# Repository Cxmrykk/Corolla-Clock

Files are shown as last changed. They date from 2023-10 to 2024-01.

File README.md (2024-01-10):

<h1 align=center>Toyota Corolla AMOLED Clock</h1>
<p align=center>Custom clock project using the LilyGo T-Display-S3 AMOLED</p>

<div align=center>
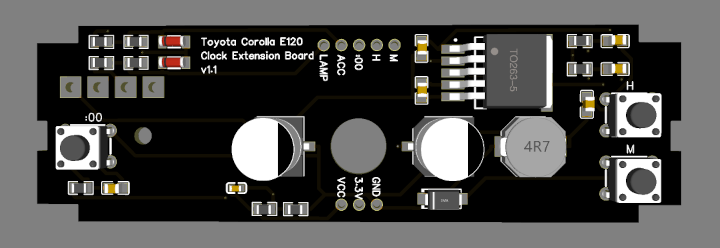
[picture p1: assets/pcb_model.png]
    
</div>

### Features
- Display the time on a high resolution AMOLED display
- Different colour/brightness based on interior lighting state (on/off)
- Colour Settings (digit colour, background opacity, whiteness level)
- Size Settings (width, thickness, padding)
- Automatic display timeout when accessory is off

### Dependencies
- **ESP-IDF** <= v4.4.6
- **Arduino-ESP32** <= v2.0.14 *(Place inside components folder)*
- **TFT-eSPI** <= v2.5.31 *(Place inside components folder)*
- **Required Libraries** (See [Official ESP-IDF Installation Steps](https://docs.espressif.com/projects/esp-idf/en/latest/esp32/get-started/linux-macos-setup.html))
    - Additionally: `python3-virtualenv`

### Configuration
- **menuconfig** *(Type "menuconfig" in Command Palette)*
    - Set all `TFT_eSPI` driver configuration pins to 0 (we are using `rm67162.h` and `rm67162.cpp` for driving the display)
    - `"Autostart Arduino setup and loop on boot"` should be enabled
- **CMakeLists.txt**
    - Make sure `main.cpp` and `rm67162.cpp` are both in `SRCS` entry for `idf_component_register`
    - `INCLUDE_DIRS` should be set to `"."` (Relative path of `main` directory, includes the header files)
- **VSCode (ESP-IDF)**
    - Set device to `esp32s3`
    - Set flash method to `UART`

### Step-by-Step DIY Tutorial
> This project requires a clock with 3 buttons (Asia/Pacific Model). If your clock does not meet this specification, you will need to purchase a separate clock housing.<br>
> A Linux-based OS is necessary to flash the software. **Debian Desktop or Ubuntu** are recommended.

1. **Procure T-Display-S3 AMOLED and Necessary Materials**
    - **T-Display-S3 Amoled** (https://www.lilygo.cc/products/t-display-s3-amoled)
    - Wire cutters
    - Soldering iron
    - Solder
    - Heat-resistant cables (compatible with 2.54mm spaced pins)

2. **Order PCB via JLCPCB Service**
    - Register an account at https://jlcpcb.com/
    - Navigate to https://cart.jlcpcb.com/quote/Upload and upload the gerber file located in `/docs/schematics`
    - Select "PCB Assembly"
    - Proceed with the checkout process, providing the files located in `docs/schematics`.

3. **Order 3D Print via JLC3DP Service**
    - Log in using the same account
    - Repeat the following process for both models:
        - Navigate to https://jlc3dp.com/3d-printing-quote and upload the STL file located in `/docs/models`
        - Choose a material that can withstand high temperatures
        - Add to cart and proceed with the checkout process

4. **Software Flashing**
    - Download Visual Studio Code from https://code.visualstudio.com
    - Install the dependencies as specified in the README
    - Follow the configuration steps as specified in the README
        - Clone the project: `git clone https://github.com/Cxmrykk/Corolla-Clock.git`
        - Navigate to the project directory: `cd Corolla-Clock`
        - Open with VSCode: `code .`
    - Connect the T-Display-S3 AMOLED board via USB-C and click the "Flash" button at the bottom

5. **Soldering Process**
    - Trim the wires on both sides (approximately 0.5cm) and tin them using the soldering iron
    - Solder wires to the T-Display-S3 AMOLED pins as follows:
        - GPIO 42: LAMP
        - GPIO 43: ACCESSORY
        - GPIO 44: RESET
        - GPIO 45: HOUR
        - GPIO 46: MINUTE
        - VBUS: VCC
        - 3.3V: 3.3V
        - GND: GND
    - After soldering, trim the ends to prevent contact (trim the top of the board, not the cables)
    - Solder the other ends of the cables to the PCB (refer to the pin map above)
    - Verify that all pins are soldered and none are touching

6. **Clock Removal and Assembly**
    - Remove the clock by following a tutorial on YouTube
    - Disassemble the clock by following a tutorial on YouTube (Exercise caution as the clock housing clips are brittle)
    - Remove the existing buttons and circuit board
    - Secure the new PCB to the clock housing using the existing screw
    - Insert the 3D printed mount and buttons (some force may be required for proper insertion)
    - Insert the Screen and PCB:
        - The USB-C port should be on the right side. The LILYGO logo should be upright (same orientation as clock housing)
        - Insert the screen first, then clip in the rest of the housing (with the PCB attached)
    - Finally, reinstall the clock and reassemble your car.

7. **Adjusting Alignment and Time**
    - Press the reset button (`:00`) to toggle the mode overlay
    - Press the hour button twice (`H`) to cycle to the vertical positioning menu
    - Press the reset button once more and hold the `H` and `M` buttons to adjust the screen position
    - Adjust the screen position as needed for clear text readability
    - Configure your clock as required (Set time, align screen, colours, sizing, brightness, etc)

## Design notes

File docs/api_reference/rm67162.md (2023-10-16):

# RM67162 C++ File Documentation

## Overview

This C++ file, `rm67162.cpp`, provides functions and commands for controlling the RM67162 display using the Arduino platform. The RM67162 is a display controller used in various TFT displays.

## Included Libraries

The file includes several libraries to support display communication and control:

- `rm67162.h`: A custom header file containing necessary declarations and constants for the RM67162 display.
- `SPI.h`: The Arduino SPI library for SPI communication.
- `Arduino.h`: The Arduino core library for general Arduino functions.
- `driver/spi_master.h`: ESP-IDF library for SPI communication on ESP32-based devices.

## Global Variables

### `rm67162_spi_init`

An array of `lcd_cmd_t` structures containing initialization commands for the RM67162 display when using SPI communication.

### `rm67162_qspi_init`

An array of `lcd_cmd_t` structures containing initialization commands for the RM67162 display when using Quad SPI (QSPI) communication.

### `spi`

A static variable of type `spi_device_handle_t` to manage SPI communication.

## Functions

### `WriteComm(uint8_t data)`

- Writes a command byte to the RM67162 display.
- Parameters:
  - `data`: The command byte to be written.

### `WriteData(uint8_t data)`

- Writes data to the RM67162 display.
- Parameters:
  - `data`: The data byte to be written.

### `WriteData16(uint16_t data)`

- Writes a 16-bit data word to the RM67162 display.
- Parameters:
  - `data`: The 16-bit data word to be written.

### `lcd_send_cmd(uint32_t cmd, uint8_t *dat, uint32_t len)`

- Sends a command and optional data to the display.
- Parameters:
  - `cmd`: The command code to be sent.
  - `dat`: An array of data bytes to be sent (can be `NULL`).
  - `len`: The length of the data to be sent.

### `rm67162_init()`

- Initializes the RM67162 display, configures the SPI communication, and sends initialization commands.

### `lcd_setRotation(uint8_t r)`

- Sets the display rotation.
- Parameters:
  - `r`: The rotation value (0, 1, 2, or 3).

### `lcd_address_set(uint16_t x1, uint16_t y1, uint16_t x2, uint16_t y2)`

- Sets the display address window for drawing operations.
- Parameters:
  - `x1`, `y1`: Coordinates of the top-left corner.
  - `x2`, `y2`: Coordinates of the bottom-right corner.

### `lcd_fill(uint16_t xsta, uint16_t ysta, uint16_t xend, uint16_t yend, uint16_t color)`

- Fills a rectangular area with a specified color.
- Parameters:
  - `xsta`, `ysta`: Coordinates of the top-left corner.
  - `xend`, `yend`: Coordinates of the bottom-right corner.
  - `color`: The fill color.

### `lcd_DrawPoint(uint16_t x, uint16_t y, uint16_t color)`

- Draws a single pixel at the specified coordinates with the given color.
- Parameters:
  - `x`, `y`: Coordinates of the pixel.
  - `color`: The pixel color.

### `lcd_PushColors(uint16_t x, uint16_t y, uint16_t width, uint16_t high, uint16_t *data)`

- Pushes an array of color data to the display at the specified coordinates.
- Parameters:
  - `x`, `y`: Coordinates of the top-left corner.
  - `width`, `high`: Width and height of the data area.
  - `data`: An array of color data.

### `lcd_PushColors(uint16_t *data, uint32_t len)`

- Pushes an array of color data to the display without specifying coordinates.
- Parameters:
  - `data`: An array of color data.
  - `len`: The length of the data.

### `lcd_sleep()`

- Puts the display to sleep mode.

### `lcd_brightness(uint8_t bright)`

- Sets the display brightness.
- Parameters:
  - `bright`: The brightness value.

### `lcd_set_colour_enhance(uint8_t enh)`

- Sets color enhancement for the display.
- Parameters:
  - `enh`: Color enhancement value.

### `lcd_display_off()`

- Turns off the display.

### `lcd_display_on()`

- Turns on the display.

### `lcd_display_invert_on()`

- Enables display inversion.

### `lcd_display_invert_off()`

- Disables display inversion.

### `lcd_display_set_colour_enhance_low_byte(uint8_t ce_low_byte)`

- Sets the low byte of color enhancement.

### `lcd_display_set_colour_enhance_high_byte(uint8_t ce_high_byte)`

- Sets the high byte of color enhancement.

### `lcd_display_high_brightness_mode_on(uint8_t hbm_en)`

- Enables high brightness mode.

### `lcd_display_high_brightness_mode_off(uint8_t hbm_en)`

- Disables high brightness mode.

## Note

- The code includes conditional compilation directives (`#if`) to support different display drivers and communication methods. Please ensure that the correct configuration is used for your specific setup.
- Some functions may not be implemented or used in your specific application. Modify the code as needed for your project.

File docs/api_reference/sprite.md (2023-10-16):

# TFT_eSprite Class Documentation

The `TFT_eSprite` class is a C++ class designed to create and manipulate sprites in RAM that can be used for efficient graphics rendering on TFT screens. It is a subclass of the `TFT_eSPI` class and inherits graphics functions from it. This class is particularly useful for creating and rendering graphics on TFT displays. 

## Constructor

### `explicit TFT_eSprite(TFT_eSPI *tft)`
- Constructor for the `TFT_eSprite` class. It takes a pointer to an instance of the `TFT_eSPI` class as a parameter and initializes a sprite.

## Destructor

### `~TFT_eSprite(void)`
- Destructor for the `TFT_eSprite` class. Deallocates memory used by the sprite.

## Sprite Creation

### `void* createSprite(int16_t width, int16_t height, uint8_t frames = 1)`
- Creates a sprite with the specified width, height, and number of frames. Returns a pointer to the RAM area used by the sprite.

### `void* getPointer(void)`
- Returns a pointer to the sprite's memory. Returns `nullptr` if the sprite has not been created.

### `bool created(void)`
- Checks if a sprite has been created and returns `true` if it has.

### `void deleteSprite(void)`
- Deletes the sprite and frees up the RAM used by it.

## Frame Buffer Selection

### `void* frameBuffer(int8_t f)`
- Selects the frame buffer for graphics write. Returns a pointer to the sprite's frame buffer.

## Color Depth

### `void* setColorDepth(int8_t b)`
- Sets the color depth of the sprite to 1, 4, 8, or 16 bits. Returns a new pointer to the sprite if it's re-created with the new depth.

### `int8_t getColorDepth(void)`
- Returns the current color depth of the sprite.

## Palette

### `void createPalette(uint16_t *palette = nullptr, uint8_t colors = 16)`
- Sets the palette for a 4-bit depth sprite. The palette is an array of 16 colors, and only the first 16 colors in the map are used.

### `void createPalette(const uint16_t *palette = nullptr, uint8_t colors = 16)`
- Sets the palette for a 4-bit depth sprite from flash memory.

### `void setPaletteColor(uint8_t index, uint16_t color)`
- Sets the color for a specific index in the palette.

### `uint16_t getPaletteColor(uint8_t index)`
- Retrieves the color at the specified palette index.

## Graphics Drawing

### `void drawPixel(int32_t x, int32_t y, uint32_t color)`
- Draws a single pixel at the specified x and y coordinates with the given color.

### `void drawChar(int32_t x, int32_t y, uint16_t c, uint32_t color, uint32_t bg, uint8_t size)`
- Draws a single character in the GLCD or GFXFF font.

### `void fillSprite(uint32_t color)`
- Fills the entire sprite with the specified color.

### `void setWindow(int32_t x0, int32_t y0, int32_t x1, int32_t y1)`
- Defines a window in the sprite for drawing, which is used for subsequent graphics operations within the defined area.

### `void pushColor(uint16_t color)`
- Pushes a single color (pixel) to the sprite's set window area.

### `void pushColor(uint16_t color, uint32_t len)`
- Pushes multiple colors (pixels) to the sprite's set window area.

### `void writeColor(uint16_t color)`
- Pushes a pre-formatted pixel with 1, 4, 8, or 16-bit color depth to the sprite's set window area.

### `void drawLine(int32_t x0, int32_t y0, int32_t x1, int32_t y1, uint32_t color)`
- Draws a line between two points with the specified color.

### `void drawFastVLine(int32_t x, int32_t y, int32_t h, uint32_t color)`
- Draws a vertical line with the specified color.

### `void drawFastHLine(int32_t x, int32_t y, int32_t w, uint32_t color)`
- Draws a horizontal line with the specified color.

### `void fillRect(int32_t x, int32_t y, int32_t w, int32_t h, uint32_t color)`
- Fills a rectangular area with the specified color, effectively drawing a filled rectangle.

## Sprite Rotation

### `void setRotation(uint8_t rotation)`
- Sets the coordinate rotation of the sprite. This is primarily for 1-bit per pixel sprites and is used for ePaper displays.

### `uint8_t getRotation(void)`
- Returns the current sprite rotation setting.

### `bool pushRotated(int16_t angle, uint32_t transp = 0x00FFFFFF)`
- Pushes a rotated copy of the sprite to the TFT screen with an optional transparent color.

### `bool pushRotated(TFT_eSprite *spr, int16_t angle, uint32_t transp = 0x00FFFFFF)`
- Pushes a rotated copy of the sprite to another different sprite with an optional transparent color.

### `bool getRotatedBounds(int16_t angle, int16_t *min_x, int16_t *min_y, int16_t *max_x, int16_t *max_y)`
- Retrieves the bounding box for a rotated copy of the sprite.

### `bool getRotatedBounds(TFT_eSprite *spr, int16_t angle, int16_t *min_x, int16_t *min_y, int16_t *max_x, int16_t *max_y)`
- Retrieves the destination sprite's bounding box for a rotated copy of this sprite.

## Miscellaneous Functions

### `uint16_t readPixel(int32_t x0, int32_t y0)`
- Reads the color of a pixel at the specified coordinates and returns the value in 565 format.

### `uint16_t readPixelValue(int32_t x, int32_t y)`
- Returns the numerical value of the pixel at the specified coordinates.

### `void pushImage(int32_t x0, int32_t y0, int32_t w, int32_t h, uint16_t *data, uint8_t sbpp = 0)`
- Writes an image (color bitmap) to the sprite.

### `void pushImage(int32_t x0, int32_t y0, int32_t w, int32_t h, const uint16_t *data)`
- Writes an image (color bitmap) to the sprite from flash memory.

### `void pushSprite(int32_t x, int32_t y)`
- Pushes the sprite to the TFT screen. Optionally, a transparent color can be defined to exclude certain pixels from rendering.

### `void pushSprite(int32_t x, int32_t y, uint16_t transparent)`
- Pushes the sprite to the TFT screen with an optional transparent color.

### `bool pushSprite(int32_t tx, int32_t ty, int32_t sx, int32_t sy, int32_t sw, int32_t sh)`
- Pushes a windowed area of

 the sprite to the TFT at specified coordinates.

### `bool pushToSprite(TFT_eSprite *dspr, int32_t x, int32_t y)`
- Pushes the sprite to another sprite at the specified coordinates.

### `bool pushToSprite(TFT_eSprite *dspr, int32_t x, int32_t y, uint16_t transparent)`
- Pushes the sprite to another sprite at the specified coordinates with an optional transparent color.

### `int16_t drawChar(uint16_t uniCode, int32_t x, int32_t y, uint8_t font)`
- Draws a single character using the loaded font at the specified position.

### `int16_t drawChar(uint16_t uniCode, int32_t x, int32_t y)`
- Draws a single character using the loaded font at the specified position.

### `int16_t width(void)`
- Returns the width of the sprite.

### `int16_t height(void)`
- Returns the height of the sprite.

## Anti-Aliased Fonts (Associated Functions)

These functions are associated with anti-aliased fonts:

### `void drawGlyph(uint16_t code)`
- Draws a single Unicode character using the loaded font.

### `void printToSprite(String string)`
- Prints a string to the sprite using the loaded font at the cursor position.

### `void printToSprite(char *cbuffer, uint16_t len)`
- Prints a character array to the sprite using the loaded font at the cursor position.

### `int16_t printToSprite(int16_t x, int16_t y, uint16_t index)`
- Prints an indexed glyph to the sprite using the loaded font at the specified coordinates.

## Private Members

- `_tft`: Pointer to an instance of the `TFT_eSPI` class.

## Protected Members

These members are accessible by derived classes:

- `_bpp`: Bits per pixel (1, 4, 8, or 16).
- `_img`: Pointer to a 16-bit sprite.
- `_img8`: Pointer to 1 and 8-bit sprite frame 1 or frame 2.
- `_img4`: Pointer to a 4-bit sprite (uses a color map).
- `_img8_1`: Pointer to frame 1.
- `_img8_2`: Pointer to frame 2.
- `_colorMap`: Color map pointer (16 entries, used with 4-bit color map).
- `_sinra`: Sine of the rotation angle in fixed point.
- `_cosra`: Cosine of the rotation angle in fixed point.
- `_created`: Indicates whether a sprite has been created and memory reserved.
- `_gFont`: Indicates if an anti-aliased font is loaded.
- `_xs`, `_ys`, `_xe`, `_ye`, `_xptr`, `_yptr`: Used for `setWindow`.
- `_sx`, `_sy`, `_sw`, `_sh`, `_scolor`: Used for scrolling.
- `_iwidth`, `_iheight`: Sprite memory image bit width and height (swapped during rotations).
- `_dwidth`, `_dheight`: Real sprite width and height (for <8bpp sprites).
- `_bitwidth`: Sprite image bit width for `drawPixel` (for <8bpp sprites, not swapped).

This class provides a wide range of functionality for creating and manipulating sprites in RAM, making it useful for graphics applications on TFT displays.

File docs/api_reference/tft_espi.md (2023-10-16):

# TFT_eSPI Documentation

The `TFT_eSPI` class provides a range of functions for controlling TFT displays. Below are the key functions and their descriptions:

## Constructor

### `TFT_eSPI(int16_t _W = TFT_WIDTH, int16_t _H = TFT_HEIGHT)`

Initialize a TFT display object with the specified width and height.

## Pixel Drawing

- `drawPixel(int32_t x, int32_t y, uint32_t color)`: Draw a single pixel at the specified coordinates with the given color.
- `drawChar(int32_t x, int32_t y, uint16_t c, uint32_t color, uint32_t bg, uint8_t size)`: Draw a character at the specified position with color and background color.
- `drawLine(int32_t xs, int32_t ys, int32_t xe, int32_t ye, uint32_t color)`: Draw a line between two points with the specified color.
- `drawFastVLine(int32_t x, int32_t y, int32_t h, uint32_t color)`: Draw a vertical line with a given height and color.
- `drawFastHLine(int32_t x, int32_t y, int32_t w, uint32_t color)`: Draw a horizontal line with a given width and color.
- `fillRect(int32_t x, int32_t y, int32_t w, int32_t h, uint32_t color)`: Fill a rectangular area with the specified color.

## Character and Text Information

- `int16_t drawChar(uint16_t uniCode, int32_t x, int32_t y, uint8_t font)`: Draw a character specified by Unicode at the given position using a specific font.
- `int16_t drawChar(uint16_t uniCode, int32_t x, int32_t y)`: Draw a character at the given position using the current font.
- `int16_t height(void)`: Get the height of the current font.
- `int16_t width(void)`: Get the width of the current font.

## Reading Pixel Color

- `uint16_t readPixel(int32_t x, int32_t y)`: Read the color of a pixel at the specified coordinates in 565 format.

## Window and Display Control

- `void setWindow(int32_t xs, int32_t ys, int32_t xe, int32_t ye)`: Set the active window on the display.
- `void pushColor(uint16_t color)`: Push (write) pixel colors to the active window.
- `void begin_nin_write()`: Start writing pixel data to the display.
- `void end_nin_write()`: End writing pixel data to the display.
- `void setRotation(uint8_t r)`: Set the display rotation to 0, 1, 2, or 3.
- `uint8_t getRotation(void)`: Read the current display rotation.
- `void setOrigin(int32_t x, int32_t y)`: Change the display origin position.
- `int32_t getOriginX(void)`: Get the X coordinate of the display origin.
- `int32_t getOriginY(void)`: Get the Y coordinate of the display origin.
- `void invertDisplay(bool i)`: Invert all displayed colors on the TFT.

## Viewport and Clipping

- `void setAddrWindow(int32_t xs, int32_t ys, int32_t w, int32_t h)`: Set the active window using coordinates and size.
- `void setViewport(int32_t x, int32_t y, int32_t w, int32_t h, bool vpDatum = true)`: Set a viewport with specified position and size.
- `bool checkViewport(int32_t x, int32_t y, int32_t w, int32_t h)`: Check if a specified area is within the viewport bounds.
- `int32_t getViewportX(void)`: Get the X coordinate of the viewport.
- `int32_t getViewportY(void)`: Get the Y coordinate of the viewport.
- `int32_t getViewportWidth(void)`: Get the width of the viewport.
- `int32_t getViewportHeight(void)`: Get the height of the viewport.
- `bool getViewportDatum(void)`: Get the viewport datum flag.
- `void frameViewport(uint16_t color, int32_t w)`: Create a border around the viewport.
- `void resetViewport(void)`: Reset the viewport to the top-left corner.

## Clipping Functions

- `bool clipAddrWindow(int32_t* x, int32_t* y, int32_t* w, int32_t* h)`: Clip a window area to the viewport bounds.
- `bool clipWindow(int32_t* xs, int32_t* ys, int32_t* xe, int32_t* ye)`: Clip a window to the viewport bounds.

## Graphics Drawing

- `void fillScreen(uint32_t color)`: Fill the entire screen with the specified color.
- `void drawRect(int32_t x, int32_t y, int32_t w, int32_t h, uint32_t color)`: Draw a rectangle with the specified size and color.
- `void drawRoundRect(int32_t x, int32_t y, int32_t w, int32_t h, int32_t radius, uint32_t color)`: Draw a rounded rectangle with the specified parameters.
- `void fillRoundRect(int32_t x, int32_t y, int32_t w, int32_t h, int32_t radius, uint32_t color)`: Fill a rounded rectangle with the specified parameters.
- `void fillRectVGradient(int16_t x, int16_t y, int16_t w, int16_t h, uint32_t color1, uint32_t color2)`: Fill a vertical gradient rectangle.
- `void fillRectHGradient(int16_t x, int16_t y, int16_t w, int16_t h, uint32_t color1, uint32_t color2)`: Fill a horizontal gradient rectangle.
- `void drawCircle(int32_t x, int32_t y, int32_t r, uint32_t color)`: Draw a circle with the specified radius and color.
- `void drawCircleHelper(int32_t x, int32_t y, int32_t r, uint8_t cornername, uint32_t color)`: Draw a circle corner with the specified parameters.
- `void fillCircle(int32_t x, int32_t y, int32_t r, uint32_t color)`: Fill a circle with the specified radius and color.
- `void fillCircleHelper(int32_t x, int32_t y, int32_t r, uint8_t cornername, int32_t delta, uint32_t color)`: Fill a circle corner with the specified parameters.
- `void drawEllipse(int16_t x, int16_t y, int32_t rx, int32_t ry, uint16_t color)`: Draw an ellipse with the specified parameters.
- `void fillEllipse(int16_t x, int16_t y, int32_t rx, int32_t ry, uint16_t color)`: Fill an ellipse with the specified parameters.
- `void drawTriangle(int32_t x1,int32_t y1, int32_t x2,int32_t y2, int32_t x3,int32_t y3, uint32_t color)`: Draw a triangle with three specified points and a color.
- `void fillTriangle(int32_t x1,int32_t y1, int32_t x2,int32_t y2, int32_t x3,int32_t y3, uint32_t color)`: Fill a triangle with three specified points and a color.

## Smooth Graphics Drawing

- `uint16_t drawPixel(int32_t x, int32_t y, uint32_t color, uint8_t alpha, uint32_t bg_color = 0x00FFFFFF)`: Draw a pixel with alpha blending.
- `void drawSmoothArc(int32_t x, int32_t y, int32_t r, int32_t ir, uint32_t startAngle, uint32_t endAngle, uint32_t fg_color, uint32_t bg_color, bool roundEnds = false)`: Draw a smooth arc.
- `void drawArc(int32_t x, int32_t y, int32_t r, int32_t ir, uint32_t startAngle, uint32_t endAngle, uint32_t fg_color, uint32_t bg_color, bool smoothArc = true)`: Draw an arc.
- `void drawSmoothCircle(int32_t x, int32_t y, int32_t r, uint32_t fg_color, uint32_t bg_color)`: Draw a smooth circle.
- `void drawSmoothRoundRect(int32_t x, int32_t y, int32_t r, int32_t ir, int32_t w, int32_t h, uint32_t fg_color, uint32_t bg_color = 0x00FFFFFF, uint8_t quadrants = 0xF)`: Draw a smooth rounded rectangle.
- `void fillSmoothRoundRect(int32_t x, int32_t y, int32_t w, int32_t h, int32_t radius, uint32_t color, uint32_t bg_color = 0x00FFFFFF)`: Fill a smooth rounded rectangle.
- `void drawSpot(float ax, float ay, float r, uint32_t fg_color, uint32_t bg_color = 0x00FFFFFF)`: Draw a spot with a specified radius.
- `void drawWideLine(float ax, float ay, float bx, float by, float wd, uint32_t fg_color, uint32_t bg_color = 0x00FFFFFF)`: Draw a wide line.
- `void drawWedgeLine(float ax, float ay, float bx, float by, float aw, float bw, uint32_t fg_color, uint32_t bg_color = 0x00FFFFFF)`: Draw a wedge line.

## Image Rendering

- `void setSwapBytes(bool swap)`: Swap the byte order for image rendering functions.
- `bool getSwapBytes(void)`: Get the current byte swap setting.
- `void drawBitmap(int16_t x, int16_t y, const uint8_t *bitmap, int16_t w, int16_t h, uint16_t fgcolor)`: Draw a bitmap image.
- `void drawXBitmap(int16_t x, int16_t y, const uint8_t *bitmap, int16_t w, int16_t h, uint16_t fgcolor)`: Draw an XBitmap image.
- `void setBitmapColor(uint16_t fgcolor, uint16_t bgcolor)`: Set the colors for 1bpp sprites.
- `void setPivot(int16_t x, int16_t y)`: Set the pivot point for rendering rotated sprites.
- `int16_t getPivotX(void)`: Get the X coordinate of the pivot point.
- `int16_t getPivotY(void)`: Get the Y coordinate of the pivot point.

## Copy Screen Blocks

- `void readRect(int32_t x, int32_t y, int32_t w, int32_t h, uint16_t *data)`: Read a block of pixels to a data buffer.
- `void pushRect(int32_t x, int32_t y, int32_t w, int32_t h, uint16_t *data)`: Write a block of pixels to the screen.

## Image Rendering from RAM and FLASH

- `void pushImage(int32_t x, int32_t y, int32_t w, int32_t h, uint16_t *data)`: Render an image from RAM.
- `void pushImage(int32_t x, int32_t y, int32_t w, int32_t h, const uint16_t *data)`: Render an image from FLASH.
- `void pushImage(int32_t x, int32_t y, int32_t w, int32_t h, uint8_t *data, bool bpp8 = true, uint16_t *cmap = nullptr)`: Render an image from RAM with 1, 4, or 8 bits per pixel.
- `void pushImage(int32_t x, int32_t y, int32_t w, int32_t h, const uint8_t *data, bool bpp8, uint16_t *cmap = nullptr)`: Render an image from FLASH with 1, 4, or 8 bits per pixel.
- `void pushMaskedImage(int32_t x, int32_t y, int32_t w, int32_t h, uint16_t *img, uint8_t *mask)`: Render an image with a 1bpp mask.

## Text Rendering

- `int16_t drawNumber(long intNumber, int32_t x, int32_t y, uint8_t font)`: Draw an integer using a specific font.
- `int16_t drawNumber(long intNumber, int32_t x, int32_t y)`: Draw an integer using the current font.
- `int16_t drawFloat(float floatNumber, uint8_t decimal, int32_t x, int32_t y, uint8_t font)`: Draw a floating-point number using a specific font and a specified number of decimal places.
- `int16_t drawFloat(float floatNumber, uint8_t decimal, int32_t x, int32_t y)`: Draw a floating-point number using the current font and a specified number of decimal places.
- `int16_t drawString(const char *string, int32_t x, int32_t y, uint8_t font)`: Draw a string using a specific font.
- `int16_t drawString(const char *string, int32_t x, int32_t y)`: Draw a string using the current font.
- `int16_t drawString(const String& string, int32_t x, int32_t y, uint8_t font)`: Draw a string using a specific font.
- `int16_t drawString(const String& string, int32_t x, int32_t y)`: Draw a string using the current font.

## Text Rendering and Font Handling Support

- `void setCursor(int16_t x, int16_t y)`: Set the cursor for text printing.
- `void setCursor(int16_t x, int16_t y, uint8_t font)`: Set the cursor and font number for text printing.
- `int16_t getCursorX(void)`: Get the current cursor X position.
- `int16_t getCursorY(void)`: Get the current cursor Y position.
- `void setTextColor(uint16_t color)`: Set the character (glyph) color only.
- `void setTextColor(uint16_t fgcolor, uint16_t bgcolor, bool bgfill = false)`: Set the character (glyph) foreground and background color.
- `void setTextSize(uint8_t size)`: Set the character size multiplier.
- `void setTextWrap(bool wrapX, bool wrapY = false)`: Turn on/off text wrapping.
- `void setTextDatum(uint8_t datum)`: Set text datum position.
- `uint8_t getTextDatum(void)`: Get the text datum.
- `void setTextPadding(uint16_t x_width)`: Set text padding (background blanking/over-write) width in pixels.
- `uint16_t getTextPadding(void)`: Get the text padding.

## Colour Conversion and Alpha Blending

- `uint16_t color565(uint8_t red, uint8_t green, uint8_t blue)`: Convert 8-bit red, green, and blue to 16-bit color.
- `uint16_t color8to16(uint8_t color332)`: Convert 8-bit color to 16-bit color.
- `uint8_t color16to8(uint16_t color565)`: Convert 16-bit color to 8-bit color.
- `uint32_t color16to24(uint16_t color565)`: Convert 16-bit color to 24-bit color.
- `uint32_t color24to16(uint32_t color888)`: Convert 24-bit color to 16-bit color.
- `uint16_t alphaBlend(uint8_t alpha, uint16_t fgc, uint16_t bgc)`: Alpha blend two colors.
- `uint16_t alphaBlend(uint8_t alpha, uint16_t fgc, uint16_t bgc, uint8_t dither)`: Alpha blend two colors with dithering.
- `uint32_t alphaBlend24(uint8_t alpha, uint32_t fgc, uint32_t bgc, uint8_t dither = 0)`: Alpha blend two 24-bit colors with optional alpha dither.

## Other Functions

- `uint32_t textcolor, textbgcolor`: Text foreground and background colors.
- `uint32_t bitmap_fg, bitmap_bg`: Bitmap foreground (bit=1) and background (bit=0) colors.
- `uint8_t textfont, textsize, textdatum, rotation`: Current font, size, text datum, and display rotation settings.

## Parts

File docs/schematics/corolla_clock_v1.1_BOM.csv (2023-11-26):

ID | Name | Designator | Footprint | Quantity | Manufacturer Part | Manufacturer | Supplier | Supplier Part | Price
1 | 330uF | C1,C5 | CAP-SMD_BD8.0-L8.3-W8.3-LS9.9-FD | 2 | EEEFT1V331GP | PANASONIC(松下) | LCSC | C178599 | 0.454
2 | 1uF | C2,C3,C4 | C0805 | 3 | CL21B105KBFNNNE | SAMSUNG(三星) | LCSC | C28323 | 0.009
3 | 33nF | C6 | C0603 | 1 | CL10B333KB8NNNC | SAMSUNG(三星) | LCSC | C21117 | 0.004
4 | 100nF | C7,C8,C9 | C0805 | 3 | CL21B104KCFNNNE | SAMSUNG(三星) | LCSC | C28233 | 0.007
5 | ZMM3V3 | D1,D3 | LL-34_L3.5-W1.5-RD | 2 | ZMM3V3-M | ST(先科) | LCSC | C8056 | 0.017
6 | SS54_C22452 | D2 | SMA_L4.4-W2.8-LS5.4-R-RD | 1 | SS54 | MDD | LCSC | C22452 | 0.038
7 | 4.7uH | L1 | IND-SMD_L8.3-W8.3_CDRH8DXX | 1 | CDRH8D43NP-4R7NC | Sumida(胜美达) | LCSC | C312980 | 0.477
8 | 10kΩ | R1,R3,R5,R7,R8,R9 | R0805 | 6 | 0805W8F1002T5E | UNI-ROYAL(厚声) | LCSC | C17414 | 0.001
9 | 4.7kΩ | R2,R4 | R0805 | 2 | 0805W8F4701T5E | UNI-ROYAL(厚声) | LCSC | C17673 | 0.002
10 | 3.3kΩ | R6 | R0805 | 1 | 0805W8F3301T5E | UNI-ROYAL(厚声) | LCSC | C26010 | 0.002
11 | PTS645SK432LFS | SW1,SW2,SW3 | KEY-TH_4P-L6.0-W6.0-P4.50-LS6.5 | 3 | PTS645SK432LFS | C&K | LCSC | C285474 | 0.082
12 | XL4015E1 | U1 | TO-263-5_L10.2-W8.9-P1.70-TL | 1 | XL4015E1 | XLSEMI(芯龙) | LCSC | C51661 | 0.664
13 | Corolla Clock Breakout | U2 |  | 1
14 | Toyota Corolla E120 (03-07) Clock Module Connector | U3 | COROLLA_CLOCK | 1

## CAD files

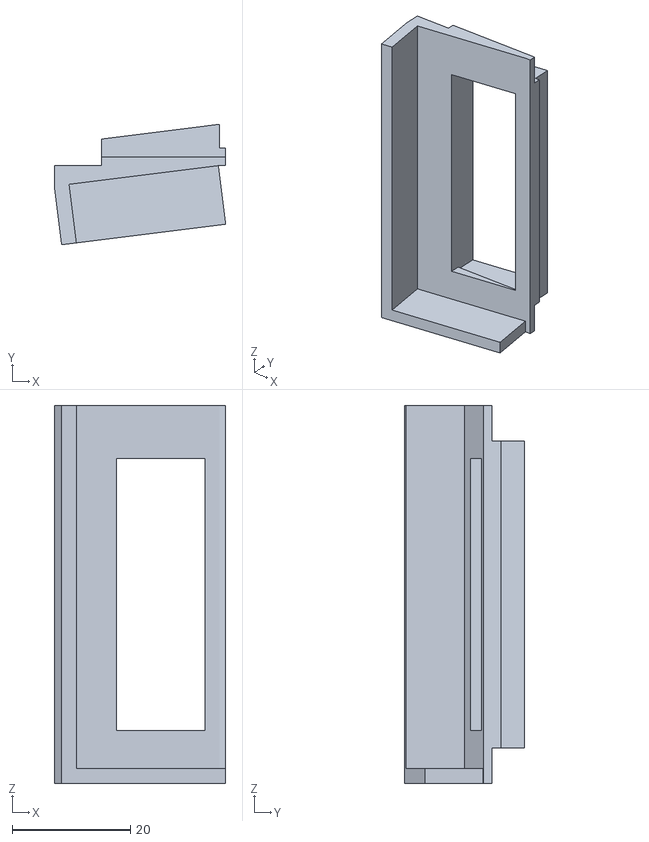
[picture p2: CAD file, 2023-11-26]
docs/models/clock_screen_mount.stl
29.0 x 20.4 x 64.0

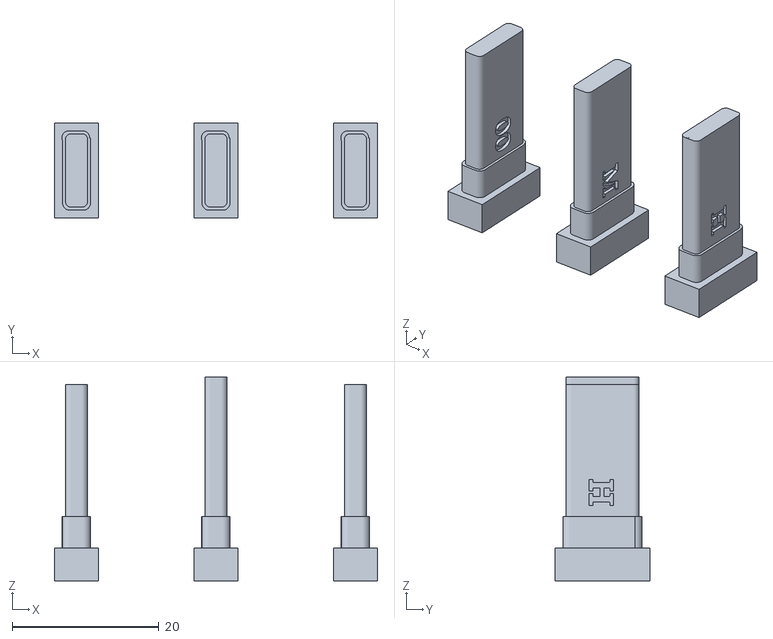
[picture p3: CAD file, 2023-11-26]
docs/models/clock_housing_buttons.stl
44.0 x 13.0 x 27.8

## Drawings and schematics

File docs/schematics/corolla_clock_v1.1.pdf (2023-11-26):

# M_INLAMP

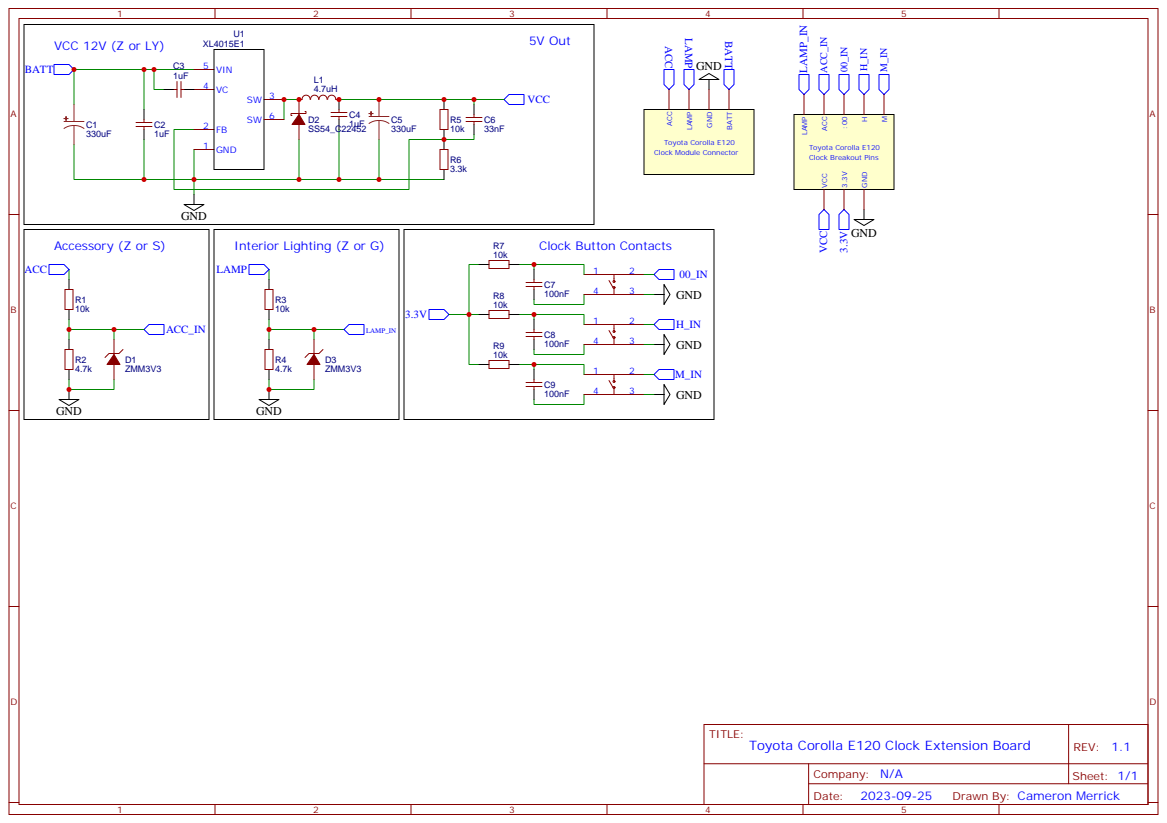
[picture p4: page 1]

Drawn By: Cameron Merrick

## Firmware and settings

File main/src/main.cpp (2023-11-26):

#include <Arduino.h>
#include <TFT_eSPI.h>
#include <esp_timer.h>
#include <freertos/FreeRTOS.h>

#include "clock.h"
#include "drivers/rm67162.h"
#include "drivers/gpio_states.h"
#include "sprites/digital_clock.h"
#include "sprites/text_display.h"
#include "sprites/tools/rgb565.h"

Clock_State_t state = {
    // Lamp off clock colours
    .lamp_off_hue = { 0, GREEN_MAXIMUM, 0 },
    .lamp_off_foreground = {0, GREEN_MAXIMUM, 0 },
    .lamp_off_background = { 0, GREEN_MAXIMUM / 10, 0 },

    // Lamp on clock colours
    .lamp_on_hue = { RED_MAXIMUM, 0, 0 },
    .lamp_on_foreground = {RED_MAXIMUM, 0, 0 },
    .lamp_on_background = { RED_MAXIMUM / 10, 0, 0 },

    // Clock state
    .timer = {
        .hour = 0,
        .minute = 0,
        .second = 0
    },

    // Digital clock configurations for lamp on and off states
    .lamp_on_digital_clock = {
        &state.timer,
        &state.lamp_on_foreground,
        &state.lamp_on_background,
        DIGIT_PADDING,
        DIGIT_WIDTH,
        DIGIT_THICKNESS
    },

    .lamp_off_digital_clock = {
        &state.timer,
        &state.lamp_off_foreground,
        &state.lamp_off_background,
        DIGIT_PADDING,
        DIGIT_WIDTH,
        DIGIT_THICKNESS
    },

    // Clock profiles for lamp on and off states
    .lamp_on_profile = {
        &state.lamp_on_digital_clock,
        &state.lamp_on_hue,
        LAMP_ON_BRIGHTNESS,
        0,
        0
    },

    .lamp_off_profile = {
        &state.lamp_off_digital_clock,
        &state.lamp_off_hue,
        LAMP_OFF_BRIGHTNESS,
        0,
        0
    },

    // Current profile
    .profile = &state.lamp_off_profile,

    // Canvas offset
    .offset = { 0, 0 },

    // Clock offset (centered)
    .clock_offset = {
        (int16_t) ((CANVAS_X - clock_width(state.profile->digital_clock)) / 2),
        (int16_t) ((CANVAS_Y - clock_height(state.profile->digital_clock)) / 2)
    },

    // Timeout event (resets when accessory is on)
    .timeout = TIMEOUT_DURATION,

    // Button toggles
    .mode_toggle = 0,
    .lamp_toggle = 0,
    .screen_toggle = 0,
    .whiteness_toggle = 0,

    .time_updated = 0,

    // Current mode
    .mode = 0,

    .tft = TFT_eSPI(),
    .sprite = TFT_eSprite(&state.tft)
};

void timer() {
    state.timer.second++;
    state.time_updated = 1;
    
    // 60 seconds have passed
    if (state.timer.second >= 60) {
        state.timer.second = 0;
        state.timer.minute++;

        // 60 minutes have passed
        if (state.timer.minute >= 60) {
            state.timer.minute = 0;
            state.timer.hour++;

            // 24 hours have passed
            if (state.timer.hour >= 24) {
                state.timer.hour = 0;
            }
        }
    }
}

void setup() {
    rm67162_init(); // amoled initialization
    lcd_setRotation(3);
    state.sprite.createSprite(SCREEN_X, SCREEN_Y);
    state.sprite.setSwapBytes(1);

    // disconnect the pin from any other peripheral functions
    gpio_pad_select_gpio(GPIO_LAMP);
    gpio_pad_select_gpio(GPIO_ACC);
    gpio_pad_select_gpio(GPIO_RESET);
    gpio_pad_select_gpio(GPIO_HOUR);
    gpio_pad_select_gpio(GPIO_MINUTE);

    // set GPIO direction
    gpio_set_direction(GPIO_LAMP, GPIO_MODE_INPUT);
    gpio_set_direction(GPIO_ACC, GPIO_MODE_INPUT);
    gpio_set_direction(GPIO_RESET, GPIO_MODE_INPUT);
    gpio_set_direction(GPIO_HOUR, GPIO_MODE_INPUT);
    gpio_set_direction(GPIO_MINUTE, GPIO_MODE_INPUT);

    // set internal pulldown by default
    gpio_set_pull_mode(GPIO_LAMP, GPIO_PULLDOWN_ONLY);
    gpio_set_pull_mode(GPIO_ACC, GPIO_PULLDOWN_ONLY);
    gpio_set_pull_mode(GPIO_RESET, GPIO_PULLDOWN_ONLY);
    gpio_set_pull_mode(GPIO_HOUR, GPIO_PULLDOWN_ONLY);
    gpio_set_pull_mode(GPIO_MINUTE, GPIO_PULLDOWN_ONLY);

    // initialise timer
    esp_timer_handle_t periodic_timer;
    const esp_timer_create_args_t periodic_timer_args = {
            .callback = (esp_timer_cb_t) &timer,
            .name = "periodic"
    };
    esp_timer_create(&periodic_timer_args, &periodic_timer);
    esp_timer_start_periodic(periodic_timer, 1000000); // 1 second interval
}

void loop() {
    timeout_handler(&state);
    gpio_handler(&state);
    draw_handler(&state);
    vTaskDelay(1000 / REFRESH_RATE);
}

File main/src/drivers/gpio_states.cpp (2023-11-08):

#include <driver/gpio.h>

#include "drivers/gpio_states.h"

void get_GPIO_states() {
    // get actual GPIO high/low state
    GPIO_active.accessory = gpio_get_level(GPIO_ACC);
    GPIO_active.lamp = gpio_get_level(GPIO_LAMP);
    GPIO_active.reset = !gpio_get_level(GPIO_RESET);
    GPIO_active.hour = !gpio_get_level(GPIO_HOUR);
    GPIO_active.minute = !gpio_get_level(GPIO_MINUTE);

    // get interpreted GPIO high/low state (button held for cycle duration)
    gpio.accessory.held = GPIO_active.accessory && GPIO_cycle.accessory == GPIO_HOLD_COUNT;
    gpio.lamp.held = GPIO_active.lamp && GPIO_cycle.lamp == GPIO_HOLD_COUNT;
    gpio.reset.held = GPIO_active.reset && GPIO_cycle.reset == GPIO_HOLD_COUNT;
    gpio.hour.held = GPIO_active.hour && GPIO_cycle.hour == GPIO_HOLD_COUNT;
    gpio.minute.held = GPIO_active.minute && GPIO_cycle.minute == GPIO_HOLD_COUNT;

    // get toggled GPIO high/low state
    gpio.accessory.pressed = gpio.accessory.held && !GPIO_toggled.accessory;
    gpio.lamp.pressed = gpio.lamp.held && !GPIO_toggled.lamp;
    gpio.reset.pressed = gpio.reset.held && !GPIO_toggled.reset;
    gpio.hour.pressed = gpio.hour.held && !GPIO_toggled.hour;
    gpio.minute.pressed = gpio.minute.held && !GPIO_toggled.minute;

    /*
        Update GPIO cycle state (number of cycles required to interpret high state)
    */
    if (GPIO_active.accessory && GPIO_cycle.accessory < GPIO_HOLD_COUNT) {
        GPIO_cycle.accessory++;
    } else if (!GPIO_active.accessory && GPIO_cycle.accessory > 0) {
        GPIO_cycle.accessory--;
    }

    if (GPIO_active.lamp && GPIO_cycle.lamp < GPIO_HOLD_COUNT) {
        GPIO_cycle.lamp++;
    } else if (!GPIO_active.lamp && GPIO_cycle.lamp > 0) {
        GPIO_cycle.lamp--;
    }

    if (GPIO_active.reset && GPIO_cycle.reset < GPIO_HOLD_COUNT) {
        GPIO_cycle.reset++;
    } else if (!GPIO_active.reset && GPIO_cycle.reset > 0) {
        GPIO_cycle.reset--;
    }

    if (GPIO_active.hour && GPIO_cycle.hour < GPIO_HOLD_COUNT) {
        GPIO_cycle.hour++;
    } else if (!GPIO_active.hour && GPIO_cycle.hour > 0) {
        GPIO_cycle.hour--;
    }

    if (GPIO_active.minute && GPIO_cycle.minute < GPIO_HOLD_COUNT) {
        GPIO_cycle.minute++;
    } else if (!GPIO_active.minute && GPIO_cycle.minute > 0) {
        GPIO_cycle.minute--;
    }

    /*
        Toggle state on
    */
    if (gpio.accessory.pressed) {
        GPIO_toggled.accessory = 1;
    }

    if (gpio.lamp.pressed) {
        GPIO_toggled.lamp = 1;
    }
    
    if (gpio.reset.pressed) {
        GPIO_toggled.reset = 1;
    }

    if (gpio.hour.pressed) {
        GPIO_toggled.hour = 1;
    }

    if (gpio.minute.pressed) {
        GPIO_toggled.minute = 1;
    }

    /*
        Toggle state off
    */
    if (!gpio.accessory.held && GPIO_toggled.accessory) {
        GPIO_toggled.accessory = 0;
    }

    if (!gpio.lamp.held && GPIO_toggled.lamp) {
        GPIO_toggled.lamp = 0;
    }

    if (!gpio.reset.held && GPIO_toggled.reset) {
        GPIO_toggled.reset = 0;
    }

    if (!gpio.hour.held && GPIO_toggled.hour) {
        GPIO_toggled.hour = 0;
    }

    if (!gpio.minute.held && GPIO_toggled.minute) {
        GPIO_toggled.minute = 0;
    }
}

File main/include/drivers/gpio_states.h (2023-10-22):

#ifndef GPIO_STATES_H
#define GPIO_STATES_H

    #include <stdint.h>

    // extension board IO
    #define GPIO_LAMP GPIO_NUM_42
    #define GPIO_ACC GPIO_NUM_43
    #define GPIO_RESET GPIO_NUM_44
    #define GPIO_HOUR GPIO_NUM_45
    #define GPIO_MINUTE GPIO_NUM_46

    // maximum loop cycles to register GPIO event (prevents noise)
    #define GPIO_HOLD_COUNT 2

    typedef struct {
        bool held;
        bool pressed;
    } GPIO_kind_t;

    typedef struct {
        GPIO_kind_t accessory;
        GPIO_kind_t lamp;
        GPIO_kind_t reset;
        GPIO_kind_t hour;
        GPIO_kind_t minute;
    } GPIO_t;

    typedef struct {
        bool accessory;
        bool lamp;
        bool reset;
        bool hour;
        bool minute;
    } GPIO_state_t;

    typedef struct {
        uint8_t accessory;
        uint8_t lamp;
        uint8_t reset;
        uint8_t hour;
        uint8_t minute;
    } GPIO_cycle_t;

    inline GPIO_t gpio = {
        {0, 0},
        {0, 0},
        {0, 0},
        {0, 0},
        {0, 0}
    };

    inline GPIO_state_t GPIO_toggled = { 0, 0, 0, 0, 0 };
    inline GPIO_state_t GPIO_active = { 0, 0, 0, 0, 0 };
    inline GPIO_cycle_t GPIO_cycle = { 0, 0, 0, 0, 0 };

    void get_GPIO_states();

#endif

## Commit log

2023-10-20 Clock spacing + Noise handling
    [main.cpp, rm67162.cpp]
2023-10-20 Moved to "/driver"
2023-10-20 Fix colour not toggling direction
    [main.cpp]
2023-10-21 Change pin 21 to 44
2023-10-21 Fix button interrupt
2023-11-07 fix text disappearing when offset < 0
    [main.cpp]
2023-11-26 set pin mode to GPIO only
2023-11-26 upload blueprints
    [clock_housing_buttons.stl, clock_screen_mount.stl, corolla_clock_v1.1_BOM.csv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]
